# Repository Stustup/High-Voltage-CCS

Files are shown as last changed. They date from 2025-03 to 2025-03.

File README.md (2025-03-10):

# High voltage constant current sorce/sink

I often need a simple low to medium current constant current source for tube amplifier projects. [Pete Millett recently released a CCS board](http://pmillett.com/CCS.html), but the integrated heatsink made it a bit too bulky for my taste and case of my DIY SET headphone amp (coming soon).

<p align="center">
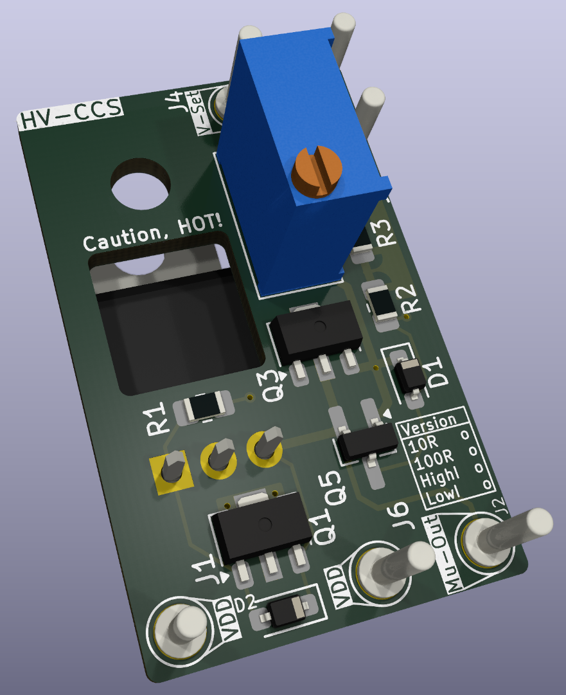
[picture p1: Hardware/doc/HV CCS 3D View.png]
    
</p>

The CCS consists of a cascaded MosFET (or JFET for the lower device) topology as per for example "Valve Amplifiers by Morgan Jones p.152 (D)". 

You have the choice on every stage on what device you want to use. The upper stage sees most of the voltage drop, so you have the choice of a TO220 and a SOT89 package. Use the TO220 for possible power dissipations of above to 1W, the SOT89 for everything below. I did this to get the footprint even smaller when you need it, e.g. Anode Resistors in small current pre stages. 

In the lower stage you can choose between a SOT89 (same as above) and a SOT23 package. For currents above 5mA use the SOT89, for currents above use the SOT89 device. The SOT23 package can be a JFET to get low noise low current sinks/sources.

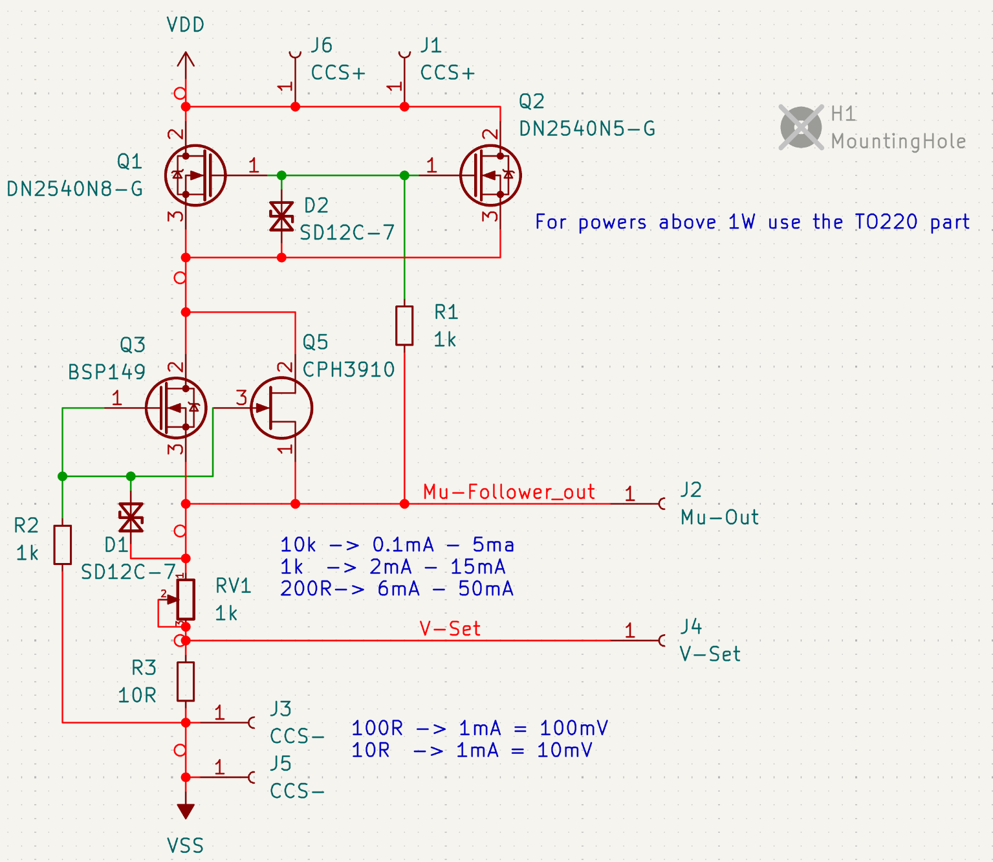
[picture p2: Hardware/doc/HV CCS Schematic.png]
Schematic of the CCS


I added TVS diodes to protect the gates of the FETS. Measuring the current can be done via the V-Set pad. Just measure between this and the VSS pin. The current can be calculated via the measured voltage times the current-set resistor R3.

You can mark on the little cute table on the right side of the PCB which version you built to prevent confusion and possibly destroyed devices. 

As for setting the CCS beforehand, i connect it to either a bench top PSU with a voltage of around 20V or, if i dont have it, to a USB-C trigger board set to 20V. You can also turn the potentiometer to the lowerst possible current, but i fat fingered this too often and set the maximum current instead, destroying a way too expensive lateral MosFET in an audio amp.

Mister Millett added a Mu-out on his board for possible MU follower configurations. I never tried it, but included it anyways for experimentation purposes. Read on (his site how to use it)[http://pmillett.com/CCS.html].

<p align="center">
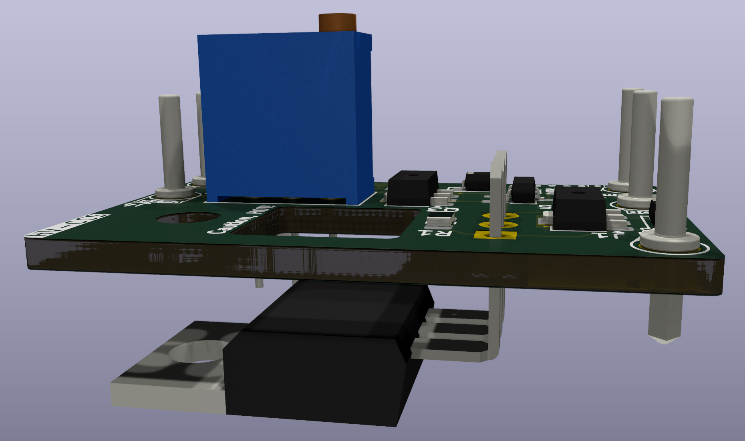
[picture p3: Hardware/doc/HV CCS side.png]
    
</p>

The board gets its small size from the (if i may say so) relatively unconventional way you mount the board and it's TO220 package to the case. you only need a single mounting hole on your amp's case, an insulation washer and a (preferrably nylon) spacer. The mounting holes are made for M3 - M3.5 bolts.

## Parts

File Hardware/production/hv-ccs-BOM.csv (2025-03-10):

Reference | Value | Mouser-Nr. | Footprint | Datasheet | Qty | DNP
D1,D2 | SD12C-7 |  | Diode_SMD:D_SOD-323_HandSoldering | https://www.mouser.de/datasheet/2/115/DIOD_S_A0009691744_1-2543273.pdf | 2
J1,J6 | CCS+ |  | Connector_Pin:Pin_D1.3mm_L11.0mm | ~ | 2
J2 | Mu-Out |  | Connector_Pin:Pin_D1.3mm_L11.0mm | ~ | 1
J3,J5 | CCS- |  | Connector_Pin:Pin_D1.3mm_L11.0mm | ~ | 2
J4 | V-Set |  | Connector_Pin:Pin_D1.3mm_L11.0mm | ~ | 1
Q1 | DN2540N8-G | DN2540N8-G | Package_TO_SOT_SMD:SOT-89-3 | https://ww1.microchip.com/downloads/en/DeviceDoc/DN2540%20B060313.pdf | 1
Q2 | DN2540N5-G | 689-DN2540N5-G | Package_TO_SOT_THT:TO-220-3_Vertical | https://ww1.microchip.com/downloads/en/DeviceDoc/DN2540%20B060313.pdf | 1
Q3 | BSP149 | DN2540N8-G | Package_TO_SOT_SMD:SOT-89-3 | https://www.mouser.de/datasheet/2/196/Infineon_BSP149_DS_v02_01_en-1226393.pdf | 1
Q5 | CPH3910 |  | Package_TO_SOT_SMD:SOT-23_Handsoldering | https://www.onsemi.com/PowerSolutions/product.do?id=CPH3910-TL-E | 1
R1,R2,RV1 | 1k | 603-RE0805FRE07330RL,81-PV36Y501C01B00 | Potentiometer_THT:Potentiometer_Bourns_3296W_Vertical,Resistor_SMD:R_0805_2012Metric_Pad1.20x1.40mm_HandSolder | ~ | 3
R3 | 10R | 71-CRCW080510R0FKEAC | Resistor_SMD:R_0805_2012Metric_Pad1.20x1.40mm_HandSolder | ~ | 1

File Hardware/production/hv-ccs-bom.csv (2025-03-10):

Reference | Value | Mouser-Nr. | Footprint | Datasheet | Qty | DNP
J1 | CCS+ |  | Connector_Pin:Pin_D1.3mm_L11.0mm | ~ | 1
J2 | Mu-Out |  | Connector_Pin:Pin_D1.3mm_L11.0mm | ~ | 1
J3 | CCS- |  | Connector_Pin:Pin_D1.3mm_L11.0mm | ~ | 1
Q1,Q3 | DN2540N8-G | DN2540N8-G | Package_TO_SOT_SMD:SOT-89-3 | https://ww1.microchip.com/downloads/en/DeviceDoc/DN2540%20B060313.pdf | 2
Q2 | DN2540N5-G | 689-DN2540N5-G | Package_TO_SOT_THT:TO-220-3_Vertical | https://ww1.microchip.com/downloads/en/DeviceDoc/DN2540%20B060313.pdf | 1
R1,R2 | 330R | 603-RE0805FRE07330RL | Resistor_SMD:R_0805_2012Metric_Pad1.20x1.40mm_HandSolder | ~ | 2
R3 | 10R | 71-CRCW080510R0FKEAC | Resistor_SMD:R_0805_2012Metric_Pad1.20x1.40mm_HandSolder | ~ | 1
RV1 | 500R | 81-PV36Y501C01B00 | Potentiometer_THT:Potentiometer_Bourns_3296W_Vertical | ~ | 1

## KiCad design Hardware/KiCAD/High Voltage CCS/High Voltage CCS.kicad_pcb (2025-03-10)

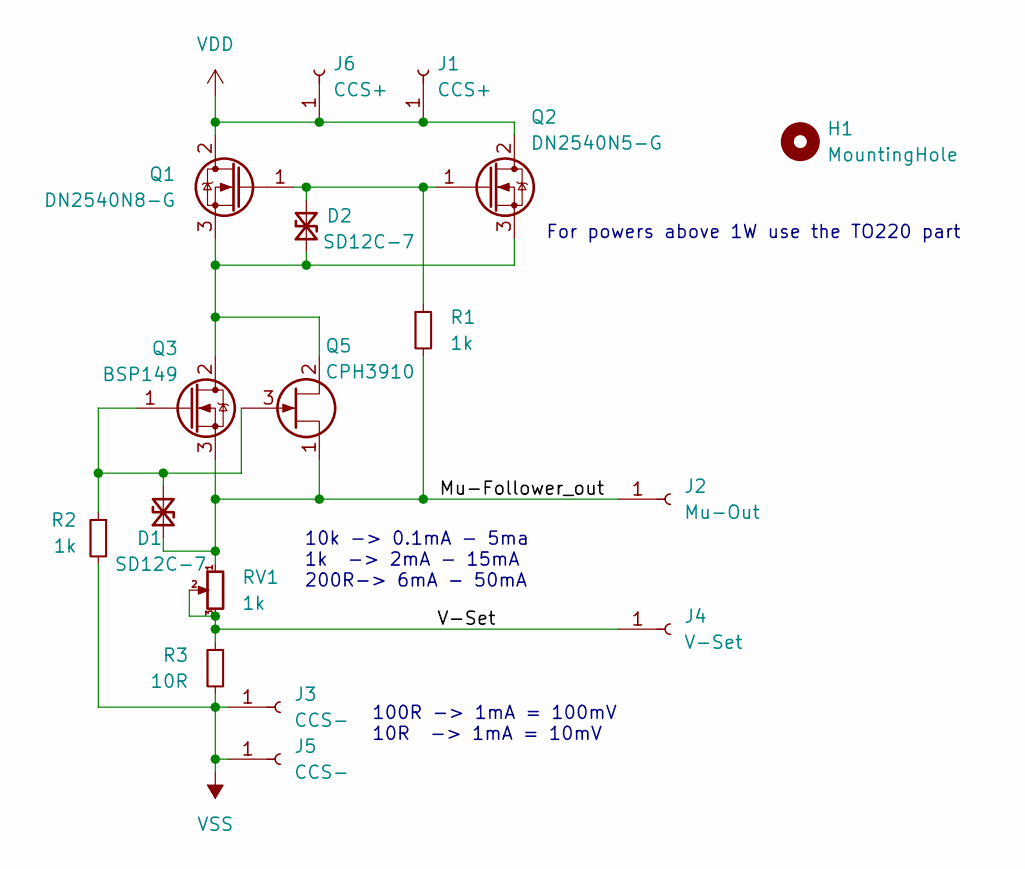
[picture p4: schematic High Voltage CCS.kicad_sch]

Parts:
D1, D2: SD12C-7; D_SOD-323_HandSoldering; Mouser Nr. 621-SD12C-7
H1: MountingHole; MountingHole_3.5mm
J1, J6: CCS+; Pin_D1.3mm_L11.0mm
J2: Mu-Out; Pin_D1.3mm_L11.0mm
J3, J5: CCS-; Pin_D1.3mm_L11.0mm
J4: V-Set; Pin_D1.3mm_L11.0mm
Q1: DN2540N8-G; SOT-89-3; Mouser-Nr. DN2540N8-G
Q2: DN2540N5-G; TO-220-3_Vertical; Mouser-Nr. 689-DN2540N5-G
Q3: BSP149; SOT-89-3; Mouser-Nr. DN2540N8-G
Q5: CPH3910; SOT-23_Handsoldering; Mouser Nr. 863-CPH3910-TL-E
R1, R2: 1k; R_0805_2012Metric_Pad1.20x1.40mm_HandSolder; Mouser-Nr. 603-RE0805FRE07330RL
R3: 10R; R_0805_2012Metric_Pad1.20x1.40mm_HandSolder; Mouser-Nr. 71-CRCW080510R0FKEAC
RV1: 1k; Potentiometer_Bourns_3296W_Vertical; Mouser-Nr. 81-PV36Y501C01B00

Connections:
/Mu-Follower_out: D1.1 (A1), J2.1, Q3.3 (S), Q5.1 (S), R1.2, RV1.1
/V-Set: J4.1, R3.1, RV1.2, RV1.3
unnamed: D1.2 (A2), Q3.1 (G), Q5.3 (G), R2.1
unnamed: D2.1 (A1), Q1.3 (S), Q2.3 (S), Q3.2 (D), Q5.2 (D)
unnamed: D2.2 (A2), Q1.1 (G), Q2.1 (G), R1.1
VDD: J1.1, J6.1, Q1.2 (D), Q2.2 (D)
VSS: J3.1, J5.1, R2.2, R3.2

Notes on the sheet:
10k -> 0.1mA - 5ma 1k -> 2mA - 15mA 200R-> 6mA - 50mA
For powers above 1W use the TO220 part
100R -> 1mA = 100mV 10R -> 1mA = 10mV

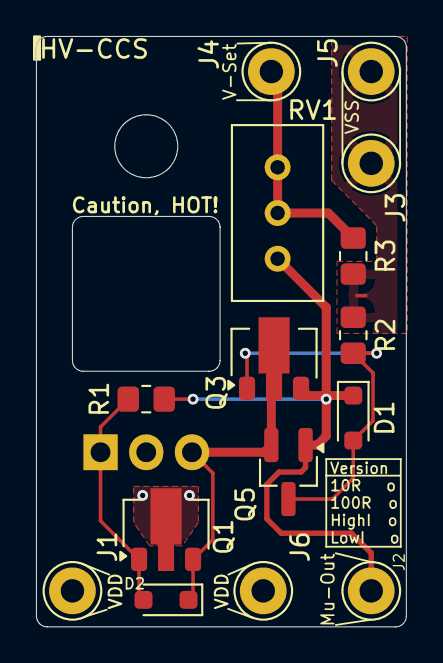
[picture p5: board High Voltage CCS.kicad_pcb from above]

Board: 2 copper layers, 20.6 x 32.8 mm, 17 parts (1 on the bottom side), 7 nets.

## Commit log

2025-03-10 added everything :)
    [High Voltage CCS-B_Cu.gbr, High Voltage CCS-B_Mask.gbr, High Voltage CCS-B_Paste.gbr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]
2025-03-10 added readme
    [High Voltage CCS.kicad_sch]
